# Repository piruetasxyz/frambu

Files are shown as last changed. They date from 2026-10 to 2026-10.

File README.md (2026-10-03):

# frambu

placa de desarrollo abierta basada en el microcontrolador **RP2040** de Raspberry Pi,
diseñada en [KiCad](https://www.kicad.org/) para fabricarse y ensamblarse en
[JLCPCB](https://jlcpcb.com/).

la documentación, con capturas del esquemático, de la placa y la lista de
materiales, está publicada en
[piruetasxyz.github.io/frambu](https://piruetasxyz.github.io/frambu/) y en
[`docs/frambu.md`](docs/frambu.md).

este repositorio se usa para trabajo colaborativo y también como material de
enseñanza: la idea es que cualquier persona pueda clonarlo, abrirlo, entender cómo
está hecho y modificarlo.

## contenidos

- [estado del proyecto](#estado-del-proyecto)
- [características de la placa](#características-de-la-placa)
- [estructura del repositorio](#estructura-del-repositorio)
- [automatizaciones (GitHub Actions)](#automatizaciones-github-actions)
- [requisitos](#requisitos)
- [cómo abrir el proyecto](#cómo-abrir-el-proyecto)
- [biblioteca local de KiCad](#biblioteca-local-de-kicad)
- [cómo trabajar en conjunto](#cómo-trabajar-en-conjunto)
- [pendientes conocidos](#pendientes-conocidos)
- [glosario](#glosario)
- [recursos para aprender](#recursos-para-aprender)
- [licencia](#licencia)

## estado del proyecto

**revisión A, en diseño.** el esquemático está avanzado y la placa tiene los
componentes ubicados, pero todavía no tiene pistas ruteadas. no está lista para
fabricar.

| revisión | carpeta | estado |
| --- | --- | --- |
| A | [`frambu-v-0-rev-a/`](frambu-v-0-rev-a/) | en diseño |

## características de la placa

| bloque | componente | notas |
| --- | --- | --- |
| microcontrolador | RP2040 (U1), LQFN-56 7×7 mm | doble núcleo ARM Cortex-M0+, hasta 133 MHz |
| memoria flash | W25Q128JVS (U3), SOIC-8 | 128 Mbit (16 MB), conectada por QSPI |
| reloj | cristal Y1 + condensadores de 15 pF (C16, C17) | señales `XIN` / `XOUT` |
| USB | conector USB-C 16 pines (J5) | USB 2.0; resistencias de 5,1 kΩ en CC1/CC2 (R6, R7) para que el cable entregue 5 V; resistencias en serie de 27,4 Ω en `USB_D+`/`USB_D-` (R1, R2) |
| alimentación | regulador lineal AMS1117 (U2) | de `VBUS` (5 V del USB) a `+3V3`; el RP2040 genera internamente `+1V1` para su núcleo |
| botón | SW1 (PTS636) | botón de arranque (BOOTSEL), en la línea `QSPI_SS` |
| pines | J3 y J4, conectores hembra de 2,54 mm | exponen `GPIO00`–`GPIO29` (`GPIO26`–`GPIO29` también son entradas analógicas `ADC0`–`ADC3`), más `RUN`, `SWCLK` y `SWD` para depuración |
| fijación | H1–H4 | agujeros para tornillos M3 |
| placa | 50 × 60 mm, 2 capas de cobre (`F.Cu`, `B.Cu`) | |

el diseño sigue de cerca la guía oficial
[Hardware design with RP2040](https://datasheets.raspberrypi.com/rp2040/hardware-design-with-rp2040.pdf),
que es la mejor referencia para entender por qué cada componente está ahí.

## estructura del repositorio

```text
frambu/
├── README.md                     este archivo
├── LICENSE                       licencia MIT
├── .gitignore                    ignora archivos temporales y de respaldo de KiCad
├── .github/workflows/            automatizaciones de GitHub Actions
├── docs/
│   ├── frambu.md              capturas y lista de materiales (BOM) de la placa
│   ├── generar_bom.py            regenera la tabla de BOM en frambu.md
│   └── images/                   capturas SVG generadas automáticamente
└── frambu-v-0-rev-a/              una carpeta por revisión de la placa
    ├── frambu-v-0-rev-a.kicad_pro proyecto de KiCad (abrir este)
    ├── frambu-v-0-rev-a.kicad_sch esquemático
    ├── frambu-v-0-rev-a.kicad_pcb diseño de la placa (PCB)
    ├── bom.csv                   lista de partes de JLCPCB, escrita a mano
    ├── sym-lib-table             registra la biblioteca local de símbolos
    ├── fp-lib-table              registra la biblioteca local de huellas
    └── bibliotecas/              biblioteca local generada desde bom.csv
        ├── frambu-v-0-rev-a.kicad_sym   símbolos
        ├── frambu-v-0-rev-a.pretty/     huellas (footprints)
        └── frambu-v-0-rev-a.3dshapes/   modelos 3D (.step y .wrl)
```

cada revisión vive en su propia carpeta para poder comparar versiones y no perder
el diseño de una placa ya fabricada.

## automatizaciones (GitHub Actions)

hay dos workflows en [`.github/workflows/`](.github/workflows/):

- [`actualizar-capturas.yml`](.github/workflows/actualizar-capturas.yml): cada
  vez que se hace push a `main` con cambios en el esquemático o la placa de la
  revisión activa, usa `kicad-cli` (KiCad 10, en docker) para exportar
  `docs/images/frambu-v-0-rev-a-esquematico.svg` y
  `docs/images/frambu-v-0-rev-a-placa.svg`, regenera la tabla de BOM en
  `docs/frambu.md` con `docs/generar_bom.py`, y hace commit de los cambios.
- [`desplegar-paginas.yml`](.github/workflows/desplegar-paginas.yml): construye
  el sitio con Jekyll y lo publica en GitHub Pages, tanto en cada push a `main`
  como al terminar el workflow anterior.

como el primer workflow hace commits, **conviene hacer `git pull` después de
cada push** que toque el esquemático o la placa.

la tabla de BOM también se puede regenerar a mano, con KiCad 10 instalado:

```bash
python3 docs/generar_bom.py
```

si se agrega una revisión nueva (por ejemplo `frambu-v-0-rev-b/`), hay que
actualizar las rutas en `actualizar-capturas.yml` y `REVISION` en
`docs/generar_bom.py`.

## requisitos

- **KiCad 10** o superior. los archivos se guardaron con KiCad 10.0 y no se
  pueden abrir en versiones anteriores.
- **git**, para clonar y colaborar.
- opcional, solo para regenerar la biblioteca local: **Python 3** y el
  repositorio [partes-jlcpcb](https://github.com/piruetasxyz/partes-jlcpcb).

## cómo abrir el proyecto

```bash
git clone https://github.com/piruetasxyz/frambu.git
cd frambu
```

luego, en KiCad: **Archivo → Abrir proyecto** y elegir
`frambu-v-0-rev-a/frambu-v-0-rev-a.kicad_pro`. desde ahí se abren el esquemático y
la placa.

no hace falta configurar nada más: los archivos `sym-lib-table` y `fp-lib-table`
del proyecto ya apuntan a la biblioteca local usando `${KIPRJMOD}`, que KiCad
reemplaza por la carpeta del proyecto. por eso funciona en cualquier computador,
sin importar dónde se clone el repositorio.

## biblioteca local de KiCad

las partes que usamos de JLCPCB se listan en `bom.csv` dentro de cada revisión
(por ejemplo `frambu-v-0-rev-a/bom.csv`). tiene las mismas columnas que el
inventario de [partes-jlcpcb](https://github.com/piruetasxyz/partes-jlcpcb):

| columna | significado |
| --- | --- |
| `Category` | tipo de componente |
| `Value` | valor (ej. `10kΩ`, `100nF`) o número de parte |
| `Footprint` | encapsulado (ej. `0402`, `SOIC-8`) |
| `JLCPCB Part #` | código LCSC, empieza con `C` (ej. `C25744`) |
| `Description` | descripción de JLCPCB |
| `Qty (fecha)` | cantidad en nuestro inventario en esa fecha; vacía si no la tenemos |

a partir de ese archivo se genera la biblioteca local (símbolos, huellas y
modelos 3D):

```bash
cd frambu-v-0-rev-a
python3 /ruta/a/partes-jlcpcb/generar_biblioteca.py --bom bom.csv --output bibliotecas/frambu-v-0-rev-a
```

ajusta `/ruta/a/partes-jlcpcb` a donde tengas clonado ese repositorio. requiere
su entorno virtual activado (ver su README).

### agregar una parte nueva

1. buscar la parte en [jlcpcb.com/parts](https://jlcpcb.com/parts) y anotar su
   código LCSC (`C…`). preferir partes **básicas** (*basic*) antes que
   **extendidas** (*extended*): las extendidas cobran un recargo de montaje por
   cada tipo de parte.
2. agregar una fila a `bom.csv`.
3. regenerar la biblioteca con el comando de arriba.
4. en el esquemático, usar el símbolo de la biblioteca `frambu-v-0-rev-a` o
   asignar la huella nueva al símbolo existente, y llenar su campo `LCSC` con el
   código de la parte.
5. hacer commit de `bom.csv` **y** de los archivos nuevos en `bibliotecas/`
   juntos, para que la otra persona no abra el proyecto con huellas faltantes.

## cómo trabajar en conjunto

los archivos de KiCad son texto, así que git los guarda bien, pero **no se
pueden fusionar (merge) de forma confiable**: si dos personas editan el mismo
`.kicad_sch` o `.kicad_pcb` a la vez, el conflicto casi siempre hay que
resolverlo a mano rehaciendo uno de los cambios. para evitarlo:

1. **avisar antes de editar.** decir quién está trabajando en el esquemático o
   en la placa, y no editar el mismo archivo al mismo tiempo.
2. **traer cambios antes de abrir KiCad:** `git pull`.
3. **cerrar KiCad antes de hacer commit**, para que todo esté guardado.
4. **commits pequeños y con mensajes claros**, en español y en minúsculas,
   describiendo el cambio (ej. `agregar cristal, mounting holes`).
5. **subir los cambios pronto:** `git push`, para que la otra persona los tenga.
6. para cambios grandes o experimentales, usar una rama y un pull request.

el `.gitignore` ya ignora lo que KiCad genera localmente y no debe subirse:
respaldos (`*-backups`), archivos de bloqueo (`~*.lck`), cachés,
`*.kicad_prl` (preferencias de ventana de cada persona) y archivos exportados
(`*.csv`, `*.xml`, `*.net`). la excepción es `bom.csv`, que sí se sube porque
lo escribimos a mano.

si KiCad dice que un archivo está bloqueado por otro usuario, probablemente
quedó un `~*.lck` de una sesión que se cerró mal; se puede borrar con KiCad
cerrado.

### antes de dar por terminada una revisión

- [ ] el esquemático pasa el **ERC** (Inspeccionar → Verificador de reglas
      eléctricas) sin errores.
- [ ] la placa pasa el **DRC** (Inspeccionar → Verificador de reglas de diseño)
      sin errores, usando las reglas de fabricación de JLCPCB.
- [ ] todos los componentes a ensamblar tienen código LCSC y huella que
      coincide con esa parte.
- [ ] la placa coincide con el esquemático (Herramientas → Actualizar PCB desde
      el esquemático, sin cambios pendientes).
- [ ] revisado en el visor 3D.

## pendientes conocidos

revisión A, a la fecha de este documento:

- la placa no tiene pistas ruteadas todavía (sí tiene una zona de cobre).
- el símbolo de U2 en el esquemático es `AMS1117-5.0` con huella SOT-223, pero
  `bom.csv` y su código LCSC (`C880752`) corresponden a un `AMS1117-3.3` en
  SOT-89-3. hay que alinearlos: la placa necesita **3,3 V**.
- R3 tiene el código LCSC `C11702` (resistencia 0402) pero huella 0805.
- R1, R2 (27,4 Ω), C16, C17 (15 pF) y Y1 (cristal) no tienen huella ni código
  LCSC asignado.
- J3 y J4 usan el símbolo de 2×18 pines pero la huella de 1×20 pines.
- varios condensadores 0805 (C1–C11) aún no tienen código LCSC en el
  esquemático, aunque sus partes ya están en `bom.csv`.

## glosario

| término | significado |
| --- | --- |
| **esquemático** | el dibujo de qué está conectado con qué, sin importar la posición física |
| **PCB** | *printed circuit board*, placa de circuito impreso; también el archivo con el diseño físico |
| **huella** (*footprint*) | la forma de cobre en la placa donde se suelda un componente |
| **símbolo** | cómo se dibuja un componente en el esquemático |
| **net** | una conexión eléctrica: todos los pines unidos por un mismo cable lógico |
| **pista** (*track*) | línea de cobre que conecta pines en la placa |
| **ERC / DRC** | verificaciones automáticas de reglas eléctricas / de diseño |
| **BOM** | *bill of materials*, lista de materiales |
| **LCSC** | distribuidor asociado a JLCPCB; sus códigos `C…` identifican cada parte |
| **SMD** | componente de montaje superficial (sin patitas que atraviesan la placa) |
| **0402, 0805, 1206** | tamaños estándar de componentes SMD en pulgadas (0805 = 0,08 × 0,05 in) |
| **QSPI** | bus de 4 líneas de datos con el que el RP2040 lee su memoria flash |
| **SWD** | *serial wire debug*, interfaz para programar y depurar el microcontrolador |
| **BOOTSEL** | modo en que el RP2040 aparece como unidad USB para cargarle programas |
| **LDO** | regulador lineal de baja caída; aquí baja 5 V a 3,3 V |

## recursos para aprender

- [documentación de KiCad](https://docs.kicad.org/) (disponible en español).
- [Hardware design with RP2040](https://datasheets.raspberrypi.com/rp2040/hardware-design-with-rp2040.pdf):
  guía oficial con un diseño mínimo de referencia, muy parecido a esta placa.
- [hoja de datos del RP2040](https://datasheets.raspberrypi.com/rp2040/rp2040-datasheet.pdf).
- [capacidades de fabricación de JLCPCB](https://jlcpcb.com/capabilities/pcb-capabilities):
  tamaños mínimos de pista, separación y perforaciones para configurar el DRC.

## licencia

[MIT](LICENSE), © 2026 piruetas.

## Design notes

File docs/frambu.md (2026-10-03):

# frambu

## Revisiones

- `v-0-rev-a`: en diseño, única revisión presente en el repositorio.

## Esquemático y placa (v-0-rev-a)

Generados automáticamente por GitHub Actions a partir de `frambu-v-0-rev-a/frambu-v-0-rev-a.kicad_sch` y `.kicad_pcb` en cada push que los modifica.

Esquemático de frambu v-0-rev-a

Placa de frambu v-0-rev-a

## Bill of materials (v-0-rev-a)

Generado a partir de `frambu-v-0-rev-a/frambu-v-0-rev-a.kicad_sch`. No confundir con `frambu-v-0-rev-a/bom.csv`, que se escribe a mano para generar la biblioteca local.

<!-- BOM_TABLE_START -->

| Referencias | Cantidad | Valor | Huella | LCSC | Descripción |
| --- | --- | --- | --- | --- | --- |
| C1, C9 | 2 | 1u | Capacitor_SMD:C_0805_2012Metric | *(sin código)* | Condensador |
| C2, C3, C4, C5, C6, C7, C8, C10, C11 | 9 | 100n | Capacitor_SMD:C_0805_2012Metric | *(sin código)* | Condensador |
| C12, C18 | 2 | 100u | frambu-v-0-rev-a:C1206 | C15008 | Condensador |
| C13, C19, C20 | 3 | 10u | frambu-v-0-rev-a:C0402 | C15525 | Condensador |
| C15 | 1 | 10u | Capacitor_SMD:CP_Elec_4x5.4 | *(sin código)* | Condensador |
| C16, C17 | 2 | 15p | *(sin huella asignada)* | *(sin código)* | Condensador |
| J3, J4 | 2 | Conn_02x18_Odd_Even | Connector_PinSocket_2.54mm:PinSocket_1x20_P2.54mm_Vertical | *(sin código)* | Conector de pines |
| J5 | 1 | USB_C_Receptacle_USB2.0_16P | frambu-v-0-rev-a:USB-C_SMD-TYPE-C-31-M-12_1 | C165948 | Conector USB-C |
| R1, R2 | 2 | 27.4 | *(sin huella asignada)* | *(sin código)* | Resistencia |
| R3 | 1 | 1k | Resistor_SMD:R_0805_2012Metric | C11702 | Resistencia |
| R4 | 1 | 10k | frambu-v-0-rev-a:R0402 | C25744 | Resistencia |
| R5 | 1 | 1K | Resistor_SMD:R_0805_2012Metric | *(sin código)* | Resistencia |
| R6, R7 | 2 | 5k1 | frambu-v-0-rev-a:R0402 | C25905 | Resistencia |
| SW1 | 1 | PTS 636 | frambu-v-0-rev-a:KEY-SMD_L6.0-W3.5-LS8.7 | C2689642 | Botón BOOTSEL |
| U1 | 1 | RP2040 | Package_DFN_QFN:QFN-56-1EP_7x7mm_P0.4mm_EP3.2x3.2mm | *(sin código)* | Microcontrolador RP2040 |
| U2 | 1 | AMS1117-5.0 | Package_TO_SOT_SMD:SOT-223-3_TabPin2 | C880752 | Regulador lineal (LDO) |
| U3 | 1 | W25Q128JVS | frambu-v-0-rev-a:SOIC-8_L5.3-W5.3-P1.27-LS8.0-BL | C97521 | Memoria flash QSPI de 128 Mbit |
| U4 | 1 | SGTL5000XNLA3 | Package_DFN_QFN:QFN-20-1EP_3x3mm_P0.4mm_EP1.65x1.65mm | *(sin código)* | Audio:SGTL5000XNLA3 |
| Y1 | 1 | Crystal_GND24 | *(sin huella asignada)* | *(sin código)* | Cristal |

35 componentes en total. Los ítems marcados *(sin huella asignada)* todavía no están completos en el esquemático — hay que completarlos antes de generar gerbers o comprar partes para esta revisión.

<!-- BOM_TABLE_END -->

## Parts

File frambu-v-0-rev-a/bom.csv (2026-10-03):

Category | Value | Footprint | JLCPCB Part # | Description | Qty (2026-09-17)
Embedded Processors & Controllers | RP2040 | LQFN-56(7x7) | C2040 | 12bit 133MHz 30 LQFN-56(7x7) Microcontrollers (MCU/MPU/SOC) ROHS | 30
Memory | W25Q128JVSIQ | SOIC-8-208mil | C97521 | -40℃~+85℃ 100000 cycles 128Mbit 133MHz 1uA 2.7V~3.6V 20 Years SPI SOIC-8-208mil NOR FLASH ROHS | 10
Connectors | TYPE-C-31-M-12 | SMD | C165948 | -30℃~+80℃ 10000 cycles 16P 20V 5A 7.35mm Female Surface Mount, Right Angle Type-C SMD USB Connectors ROHS | 150
Switches | PTS636SK25SMTRLFS | SMD,6x3.5mm | C2689642 | -40℃~+90℃ 12V 2.5N 3.7mm 50mA 6.1mm Gull Wing IP40 SPST-NO Surface Mount,Vertical SMD,6x3.5mm Tactile Switches ROHS | 150
Resistors | 1kΩ | 0805 | C2907232 | -55℃~+155℃ 125mW 150V 1kΩ Thick Film Resistor ±1% ±100ppm/℃ 0805 Chip Resistor - Surface Mount ROHS | 9925
Resistors | 10kΩ | 0805 | C17414 | -55℃~+155℃ 10kΩ 125mW 150V Thick Film Resistor ±1% ±100ppm/℃ 0805 Chip Resistor - Surface Mount ROHS | 4905
Resistors | 5.1kΩ | 0402 | C25905 | -55℃~+155℃ 5.1kΩ 50V 62.5mW Thick Film Resistor ±1% ±100ppm/℃ 0402 Chip Resistor - Surface Mount ROHS | 10
Capacitors | 100nF | 0805 | C49678 | 100nF 50V X7R ±10% 0805 Multilayer Ceramic Capacitors MLCC - SMD/SMT ROHS | 880
Capacitors | 1uF | 0805 | C77083 | 1uF 50V X7R ±10% 0805 Multilayer Ceramic Capacitors MLCC - SMD/SMT ROHS | 206
Capacitors | 10uF | SMD,D4xL5.4mm | C3357 | -55℃~+105℃ 10uF 16V 2000hrs@105℃ 4mm 5.4mm ±20% SMD,D4xL5.4mm Aluminum Electrolytic Capacitors - SMD ROHS | 1962
Capacitors | 100uF | SMD,D6.3xL7.7mm | C46550415 | -55℃~+105℃ 100uF 2000hrs@105℃ 50V 6.3mm 140mA@120Hz 7.7mm ±20% SMD,D6.3xL7.7mm Aluminum Electrolytic Capacitors - SMD ROHS | 300
Resistors | 1kΩ | 0402 | C11702 | -55℃~+155℃ 1kΩ 50V 62.5mW Thick Film Resistor ±1% ±100ppm/℃ 0402 Chip Resistor - Surface Mount ROHS
Resistors | 10kΩ | 0402 | C25744 | -55℃~+155℃ 10kΩ 50V 62.5mW Thick Film Resistor ±1% ±100ppm/℃ 0402 Chip Resistor - Surface Mount ROHS
Capacitors | 10uF | 0402 | C15525 | 10uF 6.3V X5R ±20% 0402 Multilayer Ceramic Capacitors MLCC - SMD/SMT ROHS
Capacitors | 100uF | 1206 | C15008 | 100uF 6.3V X5R ±20% 1206 Multilayer Ceramic Capacitors MLCC - SMD/SMT ROHS
Power Management (PMIC) | AMS1117-3.3 | SOT-89-3 | C880752 | -40℃~+125℃@(Tj) 1.3V@(800mA) 18V 3.3V 3mA 70dB@(120Hz) 800mA Positive SOT-89-3 Voltage Regulators - Linear Low Drop Out (LDO) ROHS

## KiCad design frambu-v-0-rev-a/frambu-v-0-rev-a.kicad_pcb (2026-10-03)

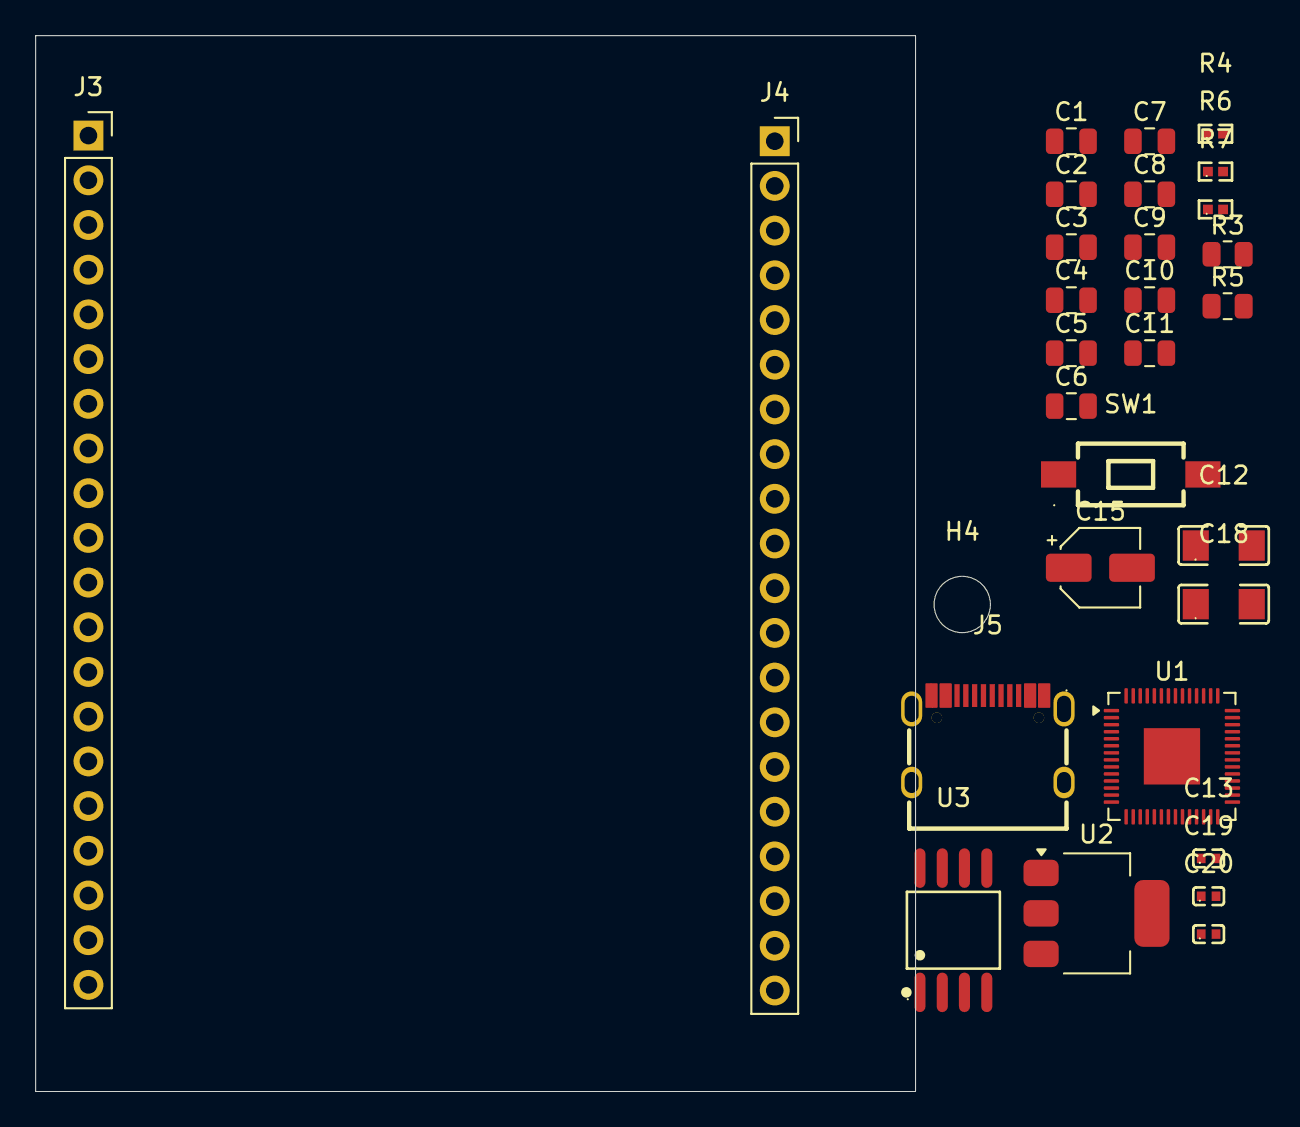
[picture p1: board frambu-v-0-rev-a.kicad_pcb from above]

Board: 2 copper layers, 50.0 x 60.0 mm, 30 parts (0 on the bottom side), 36 nets, no tracks yet.

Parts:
C1, C9: 1u; C_0805_2012Metric
C2, C3, C4, C5, C6, C7, C8, C10, C11: 100n; C_0805_2012Metric
C12, C18: 100u; C1206
C13, C19, C20: 10u; C0402
C15: 10u; CP_Elec_4x5.4
H4: MountingHole; MountingHole_3.2mm_M3
J3, J4: Conn_02x18_Odd_Even; PinSocket_1x20_P2.54mm_Vertical
J5: USB_C_Receptacle_USB2.0_16P; USB-C_SMD-TYPE-C-31-M-12_1
R3: 1k; R_0805_2012Metric
R4: 10k; R0402
R5: 1K; R_0805_2012Metric
R6, R7: 5k1; R0402
SW1: PTS 636; KEY-SMD_L6.0-W3.5-LS8.7
U1: RP2040; QFN-56-1EP_7x7mm_P0.4mm_EP3.2x3.2mm
U2: AMS1117-5.0; SOT-223-3_TabPin2
U3: W25Q128JVS; SOIC-8_L5.3-W5.3-P1.27-LS8.0-BL

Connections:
+1V1: C9.1, C10.1, C11.1, U1.23 (DVDD), U1.45 (VREG_VOUT), U1.50 (DVDD)
+3.3V: C18.1, C19.1, U2.2 (VO)
+3V3: C1.1, C2.1, C3.1, C4.1, C5.1, C6.1, C7.1, C8.1, C15.1, C20.1, J3.2, R4.1, U1.1 (IOVDD), U1.10 (IOVDD), U1.22 (IOVDD), U1.33 (IOVDD), U1.42 (IOVDD), U1.43 (ADC_AVDD), U1.44 (VREG_VIN), U1.48 (USB_VDD), U1.49 (IOVDD), U3.8 (VCC)
/GPIO00: J3.4, U1.2 (GPIO0)
/GPIO01: J3.6, U1.3 (GPIO1)
/GPIO02: J3.8, U1.4 (GPIO2)
/GPIO03: J3.10, U1.5 (GPIO3)
/GPIO04: J3.12, U1.6 (GPIO4)
/GPIO05: J3.14, U1.7 (GPIO5)
/GPIO06: J3.16, U1.8 (GPIO6)
/GPIO07: J3.18, U1.9 (GPIO7)
/GPIO08: J3.20, U1.11 (GPIO8)
/GPIO20: J4.19, U1.31 (GPIO20)
/GPIO21: J4.17, U1.32 (GPIO21)
/GPIO22: J4.15, U1.34 (GPIO22)
/GPIO23: J4.13, U1.35 (GPIO23)
/GPIO24: J4.11, U1.36 (GPIO24)
/GPIO25: J4.9, U1.37 (GPIO25)
/GPIO26_ADC0: J4.7, U1.38 (GPIO26/ADC0)
/GPIO27_ADC1: J4.5, U1.39 (GPIO27/ADC1)
/GPIO28_ADC2: J4.3, U1.40 (GPIO28/ADC2)
/GPIO29_ADC3: J4.1, U1.41 (GPIO29/ADC3)
/QSPI_SCLK: U1.52 (QSPI_SCLK), U3.6 (CLK)
/QSPI_SD0: U1.53 (QSPI_SD0), U3.5 (DI/IO_{0})
/QSPI_SD1: U1.55 (QSPI_SD1), U3.2 (DO/IO_{1})
/QSPI_SD2: U1.54 (QSPI_SD2), U3.3 (~WP/IO_{2})
/QSPI_SD3: U1.51 (QSPI_SD3), U3.7 (~HOLD/~RESET/IO_{3})
/QSPI_SS: R3.2, R4.2, U3.1 (~CS)
/USB_D+: J5.A6 (D+), J5.B6 (D+)
/USB_D-: J5.A7 (D-), J5.B7 (D-)
/XOUT: R5.2, U1.21 (XOUT)
GND: C1.2, C2.2, C3.2, C4.2, C5.2, C6.2, C7.2, C8.2, C9.2, C10.2, C11.2, C12.2, C13.2, C15.2, C18.2, C19.2, C20.2, J3.1, J3.3, J3.5, J3.7, J3.9, J3.11, J3.13, J3.15, J3.17, J3.19, J4.2, J4.4, J4.6, J4.8, J4.10, J4.12, J4.14, J4.16, J4.18, J4.20, R6.2, R7.2, SW1.1 (A), U1.19 (TESTEN), U1.57 (GND), U2.1 (GND), U3.4 (GND)
unnamed: J5.A5 (CC1), R6.1
unnamed: J5.B5 (CC2), R7.1
unnamed: R3.1, SW1.2 (B)
VHI: C12.1, C13.1, U2.3 (VI)

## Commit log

2026-10-03 agregar bibliotecas
    [bom.csv, frambuesa-rev-a.kicad_pcb, frambuesa-rev-a.kicad_sch]
2026-10-03 nombre nuevo frambu
    [bom.csv, frambu-v-0-rev-a.kicad_pcb, frambu-v-0-rev-a.kicad_sch]
2026-10-03 actualizar capturas y BOM del esquemático y la placa [skip ci]
2026-10-03 agregar sgtl500
    [frambu-v-0-rev-a.kicad_sch]
2026-10-13 agregar version de pcb
2026-10-16 agregar pcb
2026-11-10 corregidos gnd
2026-11-10 preparar archivos de fabricación para JLCPCB y marcar GPIO sin conexión
    - GPIO23, GPIO24, GPIO25 y GPIO29_ADC3 marcados sin conexión en el
    esquemático y la placa
    - nuevo docs/generar_fabricacion.py: genera frambu-v-0-rev-a-fab/
    (gerbers, taladros, zip) y frambu-v-0-rev-a-pcba/ (bom y cpl)
    - .gitignore deja pasar *-pcba/*.csv
    - README: comentarios de revisión del 2026-11-10
